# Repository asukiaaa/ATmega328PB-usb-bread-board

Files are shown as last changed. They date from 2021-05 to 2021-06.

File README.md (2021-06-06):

# ATmega328PB-usb-bread-board

## Components

- [5V 2A Diode](https://akizukidenshi.com/catalog/g/gI-02073/)
- [4.7f 0402](https://akizukidenshi.com/catalog/g/gP-07504/)
- 0.1f 0402
- 4.7uf 0402
- [MEMS 16MHz](https://akizukidenshi.com/catalog/g/gI-11094/)
- [USB microB](https://www.digikey.jp/product-detail/ja/molex/1050170001/WM1399CT-ND/2350885)
- CP2102N
- Resistor 0603 47k, 22k, 10k and 1k
- LED 0603
- [TVS Diode array ESDR0502NMUTBG](https://www.digikey.jp/product-detail/ja/on-semiconductor/ESDR0502NMUTBG/ESDR0502NMUTBGOSCT-ND/3462275)
- [Switch TVAF06](https://akizukidenshi.com/catalog/g/gP-14888/)

## License

MIT

## References

- [ATmega328PB datasheet (PDF)](http://ww1.microchip.com/downloads/en/DeviceDoc/40001906A.pdf)
- [MiniCore](https://github.com/MCUdude/MiniCore)
- [MiniCore/avr/variants/pb-variant/pins_arduino.h](https://github.com/MCUdude/MiniCore/blob/master/avr/variants/pb-variant/pins_arduino.h)
- [A-Star 328PB Micro schematic](https://www.pololu.com/file/0J1463/a-star-328pb-micro-schematic.pdf)
- [Grove system](https://wiki.seeedstudio.com/Grove_System/)
- [CP210x 5V Tolerance](https://www.silabs.com/community/interface/knowledge-base.entry.html/2004/02/18/cp210x_5v_tolerance-J582)
- [Devkitc v4 schema (PDF)](https://dl.espressif.com/dl/schematics/esp32_devkitc_v4-sch.pdf)

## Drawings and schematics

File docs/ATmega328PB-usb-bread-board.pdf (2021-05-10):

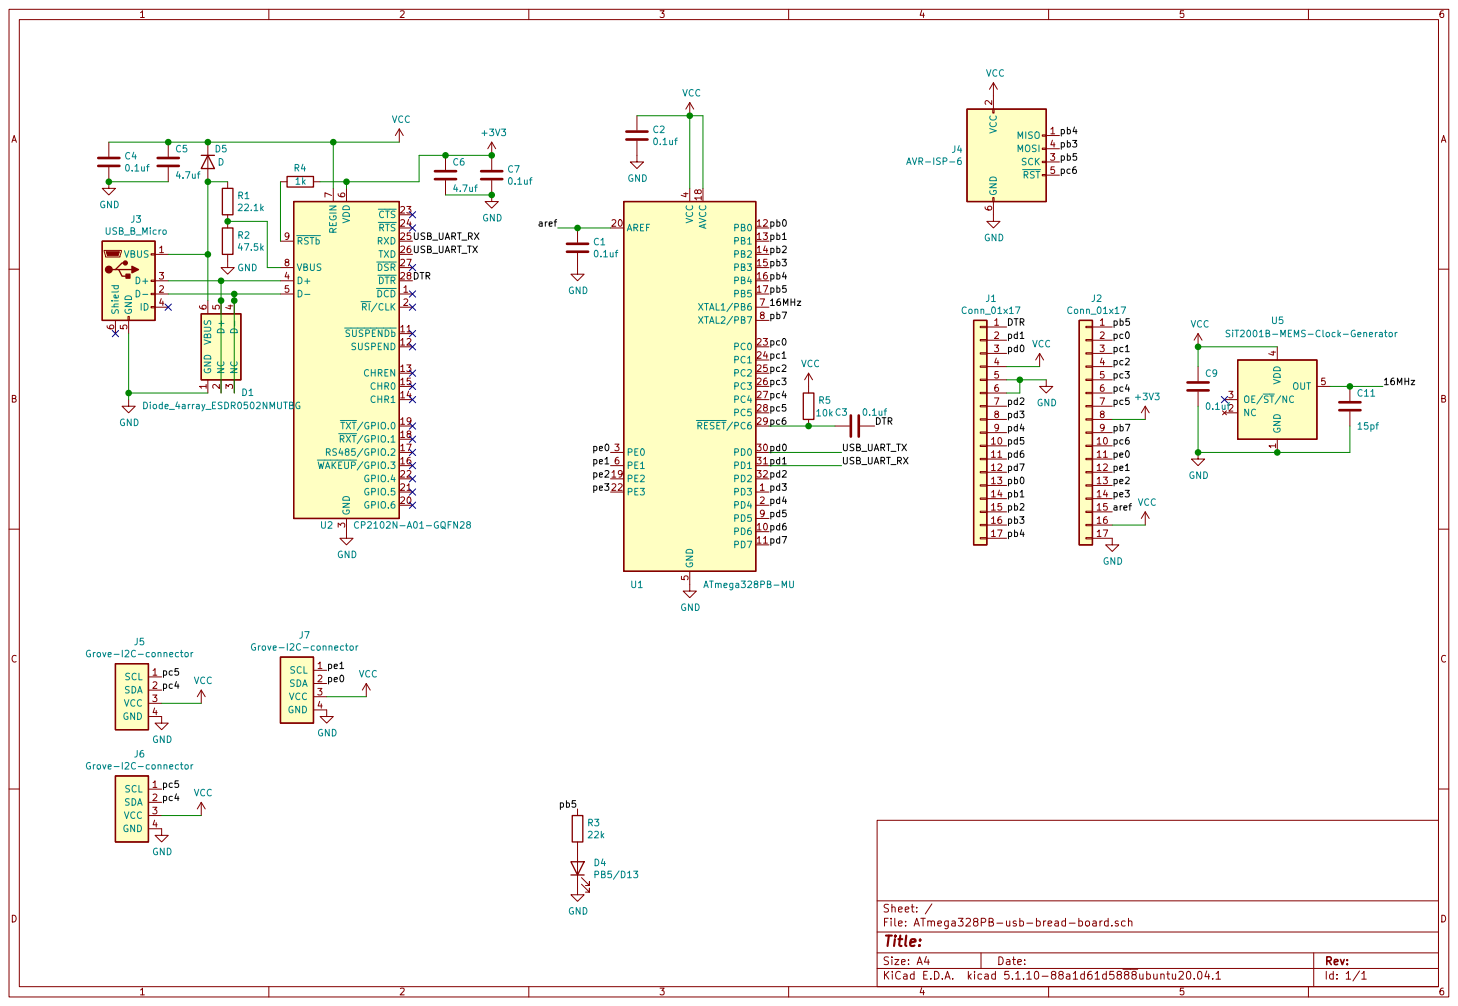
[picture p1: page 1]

2 SCK 3 MOSI 4 RST 5 GND

4 OUT 5 U5 SiT2001B-MEMS-Clock-Generator VCC GND

1 NC 2 OE/ST/NC 3 VDD

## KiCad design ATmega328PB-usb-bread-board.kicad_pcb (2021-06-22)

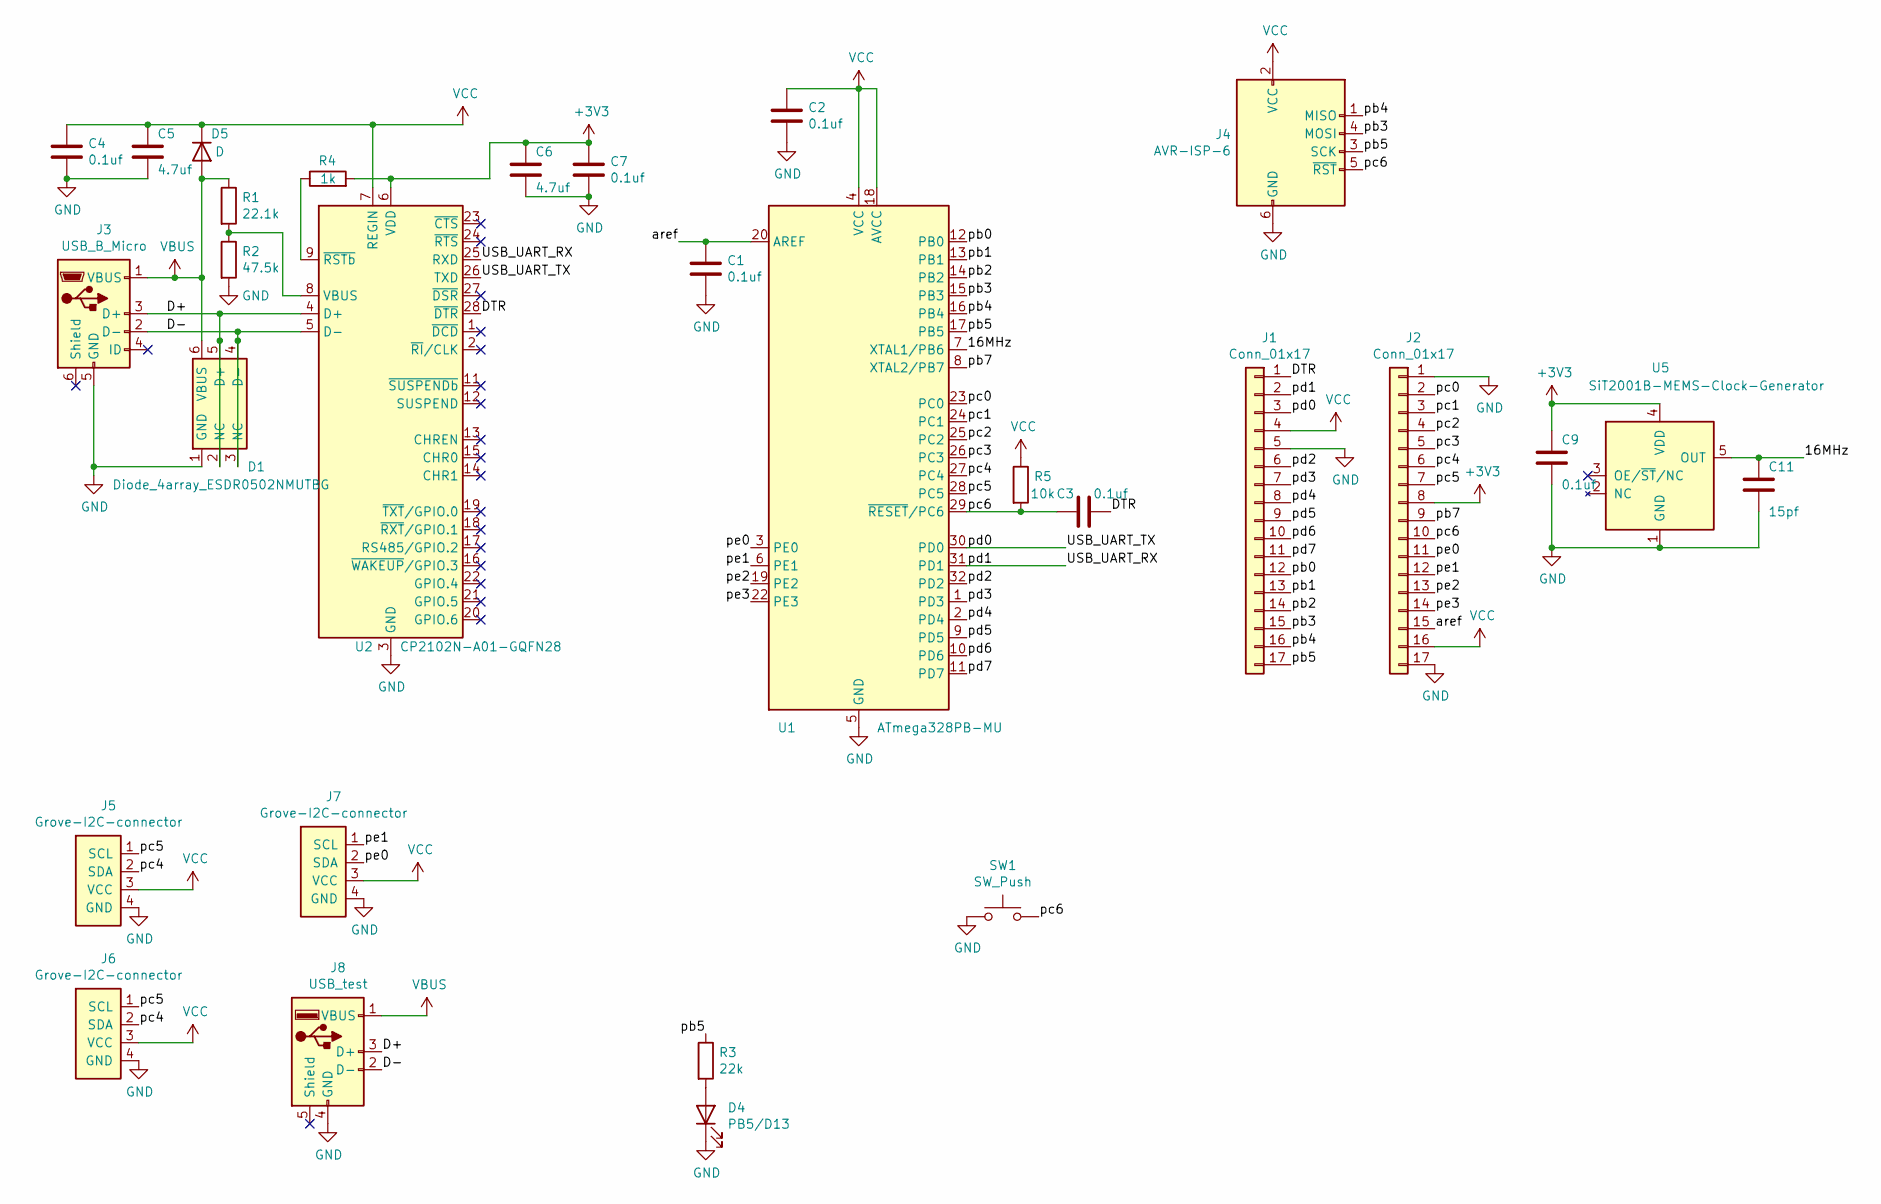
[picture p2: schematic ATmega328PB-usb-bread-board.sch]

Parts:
C1, C2, C3, C4, C7, C9: 0.1uf; C_0402_1005Metric
C5, C6: 4.7uf; C_0402_1005Metric
C11: 15pf; C_0603_1608Metric
D1: Diode_4array_ESDR0502NMUTBG; OnSemi_UDFN-6_1.2x1.0mm_P0.4mm
D4: PB5/D13; LED_0603_1608Metric_Pad1.05x0.95mm_HandSolder
D5: D; D_SOD-123F
J1, J2: Conn_01x17; PinSocket_1x17_P2.54mm_Vertical
J3: USB_B_Micro; USB_Micro-B_Molex-105017-0001
J4: AVR-ISP-6; 2x03_P2.54mm_ISP_Pads
J5, J6, J7: Grove-I2C-connector; NS-Tech_Grove_1x04_P2mm_Vertical
J8: USB_test; 2x02_P2.54mm_USB_Pads
R1: 22.1k; R_0603_1608Metric
R2: 47.5k; R_0603_1608Metric
R3: 22k; R_0603_1608Metric
R4: 1k; R_0603_1608Metric
R5: 10k; R_0603_1608Metric
SW1: SW_Push; SW_Push_TVAF06
U1: ATmega328PB-MU; QFN-32-1EP_5x5mm_P0.5mm_EP3.1x3.1mm
U2: CP2102N-A01-GQFN28; QFN-28-1EP_5x5mm_P0.5mm_EP3.35x3.35mm
U5: SiT2001B-MEMS-Clock-Generator; SOT-23-5

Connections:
+3V3: C6.1, C7.1, C9.1, J2.8, R4.2, U2.6 (VDD), U5.4 (VDD)
/16MHz: C11.1, U1.7 (XTAL1/PB6), U5.5 (OUT)
/D+: D1.2 (NC), D1.5 (D+), J3.3 (D+), J8.3 (D+), U2.4 (D+)
/D-: D1.3 (NC), D1.4 (D-), J3.2 (D-), J8.2 (D-), U2.5 (D-)
/DTR: C3.2, J1.1, U2.28 (~DTR)
/USB_UART_RX: J1.2, U1.31 (PD1), U2.25 (RXD)
/USB_UART_TX: J1.3, U1.30 (PD0), U2.26 (TXD)
/aref: C1.1, J2.15, U1.20 (AREF)
/pb0: J1.12, U1.12 (PB0)
/pb1: J1.13, U1.13 (PB1)
/pb2: J1.14, U1.14 (PB2)
/pb3: J1.15, J4.4 (MOSI), U1.15 (PB3)
/pb4: J1.16, J4.1 (MISO), U1.16 (PB4)
/pb5: J1.17, J4.3 (SCK), R3.1, U1.17 (PB5)
/pb7: J2.9, U1.8 (XTAL2/PB7)
/pc0: J2.2, U1.23 (PC0)
/pc1: J2.3, U1.24 (PC1)
/pc2: J2.4, U1.25 (PC2)
/pc3: J2.5, U1.26 (PC3)
/pc4: J2.6, J5.2 (SDA), J6.2 (SDA), U1.27 (PC4)
/pc5: J2.7, J5.1 (SCL), J6.1 (SCL), U1.28 (PC5)
/pc6: C3.1, J2.10, J4.5 (~RST), R5.2, SW1.2, U1.29 (~RESET~/PC6)
/pd2: J1.6, U1.32 (PD2)
/pd3: J1.7, U1.1 (PD3)
/pd4: J1.8, U1.2 (PD4)
/pd5: J1.9, U1.9 (PD5)
/pd6: J1.10, U1.10 (PD6)
/pd7: J1.11, U1.11 (PD7)
/pe0: J2.11, J7.2 (SDA), U1.3 (PE0)
/pe1: J2.12, J7.1 (SCL), U1.6 (PE1)
/pe2: J2.13, U1.19 (PE2)
/pe3: J2.14, U1.22 (PE3)
GND: C1.2, C2.2, C4.2, C5.2, C6.2, C7.2, C9.2, C11.2, D1.1 (GND), D4.1 (K), J1.5, J2.1, J2.17, J3.5 (GND), J4.6 (GND), J5.4 (GND), J6.4 (GND), J7.4 (GND), J8.4 (GND), R2.2, SW1.1, U1.5 (GND), U1.21 (GND), U1.33 (GND), U2.3 (GND), U2.29 (GND), U5.1 (GND)
unnamed: D4.2 (A), R3.2
unnamed: R1.2, R2.1, U2.8 (VBUS)
unnamed: R4.1, U2.9 (~RSTb)
VBUS: D1.6 (VBUS), D5.2 (A), J3.1 (VBUS), J8.1 (VBUS), R1.1
VCC: C2.1, C4.1, C5.1, D5.1 (K), J1.4, J2.16, J4.2 (VCC), J5.3 (VCC), J6.3 (VCC), J7.3 (VCC), R5.1, U1.4 (VCC), U1.18 (AVCC), U2.7 (REGIN)

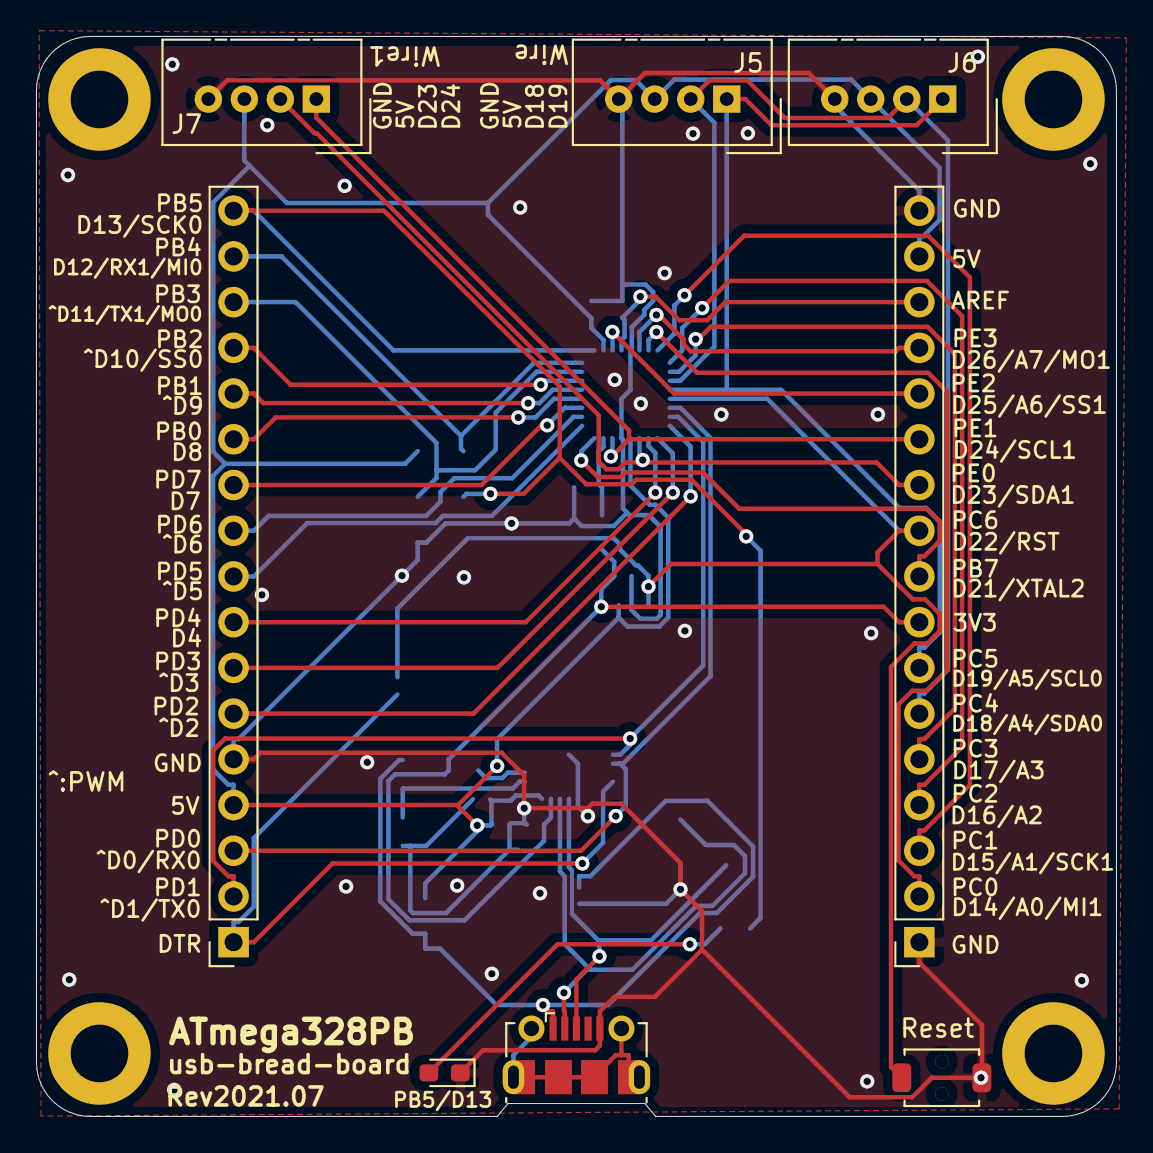
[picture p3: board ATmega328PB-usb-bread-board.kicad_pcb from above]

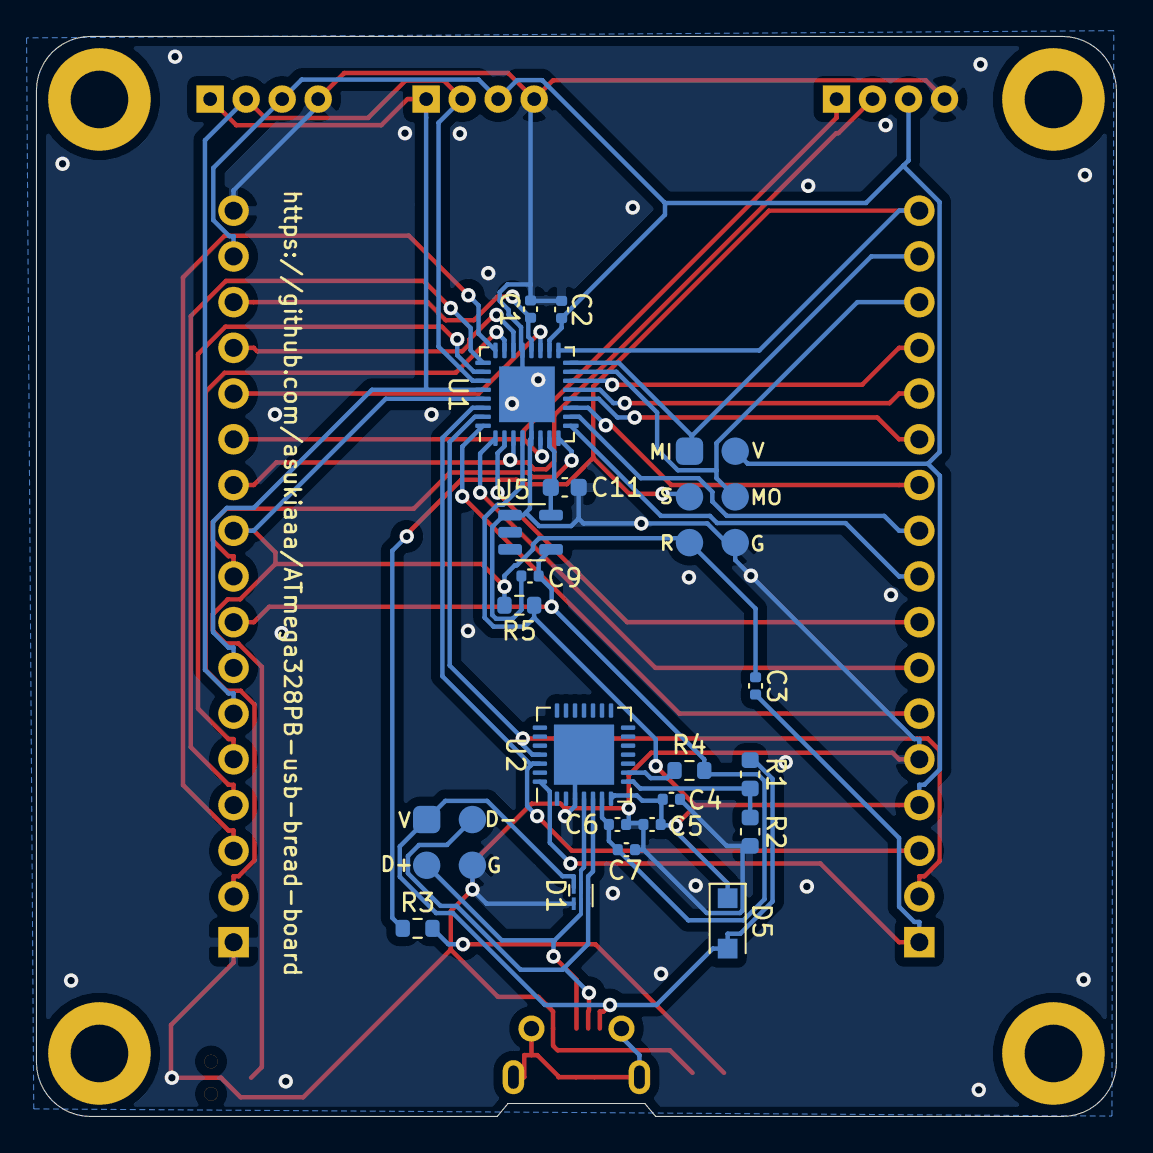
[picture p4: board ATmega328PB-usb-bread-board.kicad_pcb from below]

Board: 2 copper layers, 60.0 x 60.0 mm, 33 parts (21 on the bottom side), 38 nets.

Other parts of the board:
REF1, REF2, REF3, REF4: MountingHole_3.2mm_M3_ISO7380_Pad

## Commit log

2020-10-18 Put 3V3 regulator and 16MHz MEMS to shematic
    [ATmega328PB-usb-bread-board.sch]
2020-10-20 Add pullup resister and condensors for cp2102n
    [ATmega328PB-usb-bread-board.sch]
2020-10-20 Supply 3V3 to cp2102
    [ATmega328PB-usb-bread-board.sch]
2020-10-20 Remove jumper for DTR
    [ATmega328PB-usb-bread-board.sch]
2020-10-20 Use cp2102 as 3v3 regulator
    [ATmega328PB-usb-bread-board.sch]
2020-10-20 Add CP2102 5V tolerance info to readme
2020-10-20 Change diode position on schema
    [ATmega328PB-usb-bread-board.sch]
2020-10-20 Remove jumper for AVCC
    [ATmega328PB-usb-bread-board.sch]
2020-10-20 Update pcb
    [ATmega328PB-usb-bread-board.kicad_pcb]
2020-10-20 Update revision to 2020.11
    [ATmega328PB-usb-bread-board.kicad_pcb]
2020-11-03 Change zenar and change position of led and usb
    [ATmega328PB-usb-bread-board.kicad_pcb, ATmega328PB-usb-bread-board.sch]
2021-03-13 Use diode array and update holes position as Rev2021.03
    [ATmega328PB-usb-bread-board.kicad_pcb, ATmega328PB-usb-bread-board.sch]
2021-04-11 Correct pin asign for Wire1 grove connector
    [ATmega328PB-usb-bread-board.kicad_pcb, ATmega328PB-usb-bread-board.sch]
2021-04-12 Add pullup resistor to RST
    [ATmega328PB-usb-bread-board.kicad_pcb, ATmega328PB-usb-bread-board.sch]
2021-04-12 Add labels about pins for Grove connectors
    [ATmega328PB-usb-bread-board.kicad_pcb]
2021-04-12 Rename VCC label to 5V
    [ATmega328PB-usb-bread-board.kicad_pcb]
2021-04-12 Update revision to Rev2021.04
    [ATmega328PB-usb-bread-board.kicad_pcb]
2021-04-12 Expand pad for diode array
    [ATmega328PB-usb-bread-board.kicad_pcb]
2021-04-29 Remove amplifier
    [ATmega328PB-usb-bread-board.sch]
2021-04-29 Update footprint position of mems
    [ATmega328PB-usb-bread-board.kicad_pcb]
2021-04-29 Update a list of components and update label for resistors
    [ATmega328PB-usb-bread-board.kicad_pcb, ATmega328PB-usb-bread-board.sch]
2021-05-10 Update fill
    [ATmega328PB-usb-bread-board.kicad_pcb]
2021-05-10 Correct pin label for wire connector
    [ATmega328PB-usb-bread-board.kicad_pcb]
2021-05-17 Supply 3V3 for mems
    [ATmega328PB-usb-bread-board.kicad_pcb, ATmega328PB-usb-bread-board.sch]
2021-05-17 Update revision to 2021.06
    [ATmega328PB-usb-bread-board.kicad_pcb]
2021-05-18 Add USB pads
    [ATmega328PB-usb-bread-board.kicad_pcb, ATmega328PB-usb-bread-board.sch]
2021-06-06 Add reset button
    [ATmega328PB-usb-bread-board.kicad_pcb, ATmega328PB-usb-bread-board.sch]
2021-06-06 Add link of switch to readme
2021-06-08 Fill again
    [ATmega328PB-usb-bread-board.kicad_pcb]
2021-06-22 Change position of D13
    [ATmega328PB-usb-bread-board.kicad_pcb, ATmega328PB-usb-bread-board.sch]
2021-06-22 Update to Rev2021.07
    [ATmega328PB-usb-bread-board.kicad_pcb]
